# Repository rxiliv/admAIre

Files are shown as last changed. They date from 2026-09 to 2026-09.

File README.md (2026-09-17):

# AdmAIre: Wearable Assistance System for the Blind

AdmAIre is a cutting-edge wearable electronic device, in the form of a pair of simple glasses, designed to enhance the autonomy and safety of blind or visually impaired individuals. Through the integration of artificial intelligence and computer vision, the device analyzes the surrounding environment in real-time, providing interactive and intuitive voice assistance.

## Project Overview
The goal of AdmAIre is to bridge the gap between the user and the physical environment. Not only the system quickly detects the obstacles in the user's way, communicating essential information through an integrated audio interface, but it also allows the user to ask anything, as if they were talking to a person nearby, but keeping their full independence.

## System Architecture
The system is based on a low-latency circular data flow:
1. **Acquisition:** The wearable captures images (camera) and eventual voice inputs.
2. **Transmission:** Data is sent via **Wi-Fi connection** to the OpenRouter AI model (through the API).
3. **Processing:** The AI models process the data (Object Detection, OCR, Scene Description).
4. **Feedback:** The AI sends the text response back to the glasses, which plays it through the integrated output devices.

## Key Features

### Implemented Features

**Surroundings Analysis**
* **Object and Scene Recognition:** Real-time identification of potentially dangerous everyday elements.
* **Quick and Brief Alerts:** When near to obstacles, the device immediately detects the danger and warns the user.
* **Text Reading (OCR):** Ability to read labels, menus, or road signs in real-time.

**Well-thought-out Design**
* **Ergonomic Glasses:** Lightweight and discreet device, optimized for prolonged use.
* **No Hearing Obstruction:** Bone conduction speakers, studied to avoid obstructing the ears and keep the hearing unimpaired.
* **Customizable Frame and Structure:** Fully editable as one's wish, as the 3D model of the glasses are free to use and modify (check `license` for further information).

**Source-Available Project**

The project was made to be free for everyone to use, edit and improve, based on one's own preferences, ideas, and much more, as long as the project terms and conditions of the license, available in the `root` folder, are respected.

* **Source Code Available:** The microcontroller's C++ code is downloadable and editable.
* **Free-to-use 3D Model:** The eyeglasses frame is also available, ready for alterations, or directly for the 3D printer.
* **Guide for the Hardware:** The electrical schematics and the documentation is thought for people to understand how the prototype works and to use as they prefer.

### Planned Features
**Advanced Surroundings Analysis**
* **AI Voice Interface (NLP):** Two-way communication that allows the user to ask questions such as: *"Is there a free chair near me?"* or *"What bus number is arriving?"*.

**Advanced User Assistance**
* **Voice Activation:** The user can speak with the AI assistance through the phrase "Hey AdmAIre", captured by the integrated microphone.
* **API for Travel Details:** The AI assistance can give the user directions to get to a specific place when asked, through the implementation of an API.

## Technical Architecture

### Hardware
The prototype is based on the **XIAO ESP32-S3 Sense** microcontroller.
The electronic schematics may be found within the `pcb` folder.

**Components List**
* **Microcontroller:** Seeed Studio XIAO ESP32S3 Sense (with camera and microphone).
* **Battery:** LiPo 3.7V 803450 (1500mAh).
* **Audio Amplifiers:** MAX98357A I2S 3W DAC (x2).
* **Bone Conduction Speakers:** 8 Ohm Magnetic, 1W (x2).
* **Slide Switch:** Slide Switch (SPST) for power-on/off.
* **Resistors:** 100-200kΩ Resistors (x2).

The eyeglasses frame prototype is made through a 3D printer (PLA).
The 3D model is available in the `cad` folder, both as a one-piece and subdivided in `.stl` format, making it suitable for small 3D printers as well.

### Software
The main code resides in the microcontroller and can be found in the `firmware` folder.
The software is made through Arduino IDE.

**Code Content**
* **Microcontroller Code:** Code that allows the ESP32-S3 to send and receive radio signals, transmit the AI responses, and all the features mentioned above.
* **Simple HTML page:** Simple page for testing the device and debugging.

**Features and Technologies**
* **OpenRouter API:** Implementation of the OpenRouter API to use optimized AI models to analyze images and to respond to user queries in natural language.
* **Text-to-Speech (TTS) & STT:** Low-latency voice engines for fluid interaction.
* **Optimization of Energy Consumption:** Optimized code for minimal energy waste.

## Usage Instructions

To be able to recreate the prototype personally, all the information and resources are already present in the repository.
For the source code, the only things that need to be added are in `esp32s3.h`:
* **Wi-Fi SSID**: The name of the network the ESP32-S3 has to connect to. 
* **Wi-FI password**: The password of the network. 
* **OpenRouter API Key**: The API Key can be easily obtained from the OpenRouter services. 

**Please Note**: The AI model chosen by default in the source code is the Nvidia Nemotron 3 Nano Omni, a free model. Any other AI model that can have in input photos and audio and have text output can be used, as long as the code gets updated adequately.

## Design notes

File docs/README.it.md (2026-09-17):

# AdmAIre: Sistema di Assistenza Indossabile per i Non Vedenti

AdmAIre è un dispositivo elettronico indossabile all'avanguardia studiato per accrescere l'autonomia e la sicurezza delle persone non vedenti o ipovedenti. Con l'integrazione dell'intelligenza artificiale, il dispositivo analizza l'ambiente circostante in tempo reale, fornendo un'assistenza vocale interattiva e intuitiva.

## Panoramica del Progetto
L'obiettivo principale di AdmAIre è quello di creare un ponte solido tra l'utente e l'ambiente fisico. Questo sistema non solo rileva gli ostacoli di fronte all'utente, comunicando le informazioni essenziali attraverso un'interfaccia audio integrata, ma permette anche all'utente di chiedere qualunque cosa, come se stesse parlando con una persona accanto a sé, ma mantenendo la loro totale indipendenza.

## Architettura di Sistema
Il sistema è basato su un flusso di dati circolare a bassa latenza:
1. **Acquisizione:** Gli occhiali catturano immagini, attraverso la telecamera integrata, ed eventuali input vocali.
2. **Trasmissione:** I dati vengono trasmessi tramite **Connessione Wi-Fi** al modello AI di OpenRouter (tramite l'API).
3. **Elaborazione:** I modelli AI elaborano i dati (Object Detection, OCR, Scene Description).
4. **Feedback:** Il modello manda indietro la risposta in formato testo agli occhiali, che la riproducono tramite i dispositivi di output integrati.

## Funzionalità Chiave

### Funzionalità Attualmente Implementate

**Analisi delle Circostanze**
* **Riconoscimento di Oggetti e Scene:** Identificazione in tempo reale di elementi quotidiani che possono costituire un pericolo.
* **Avvisi Veloci e Brevi:** Quando l'utente si trova vicino ad ostacoli, il dispositivo rileva immediatamente il pericolo e avvisa l'utente.
* **Lettura di Testi (OCR):** Abilità di leggere etichette, menù o segnali stradali in tempo reale.

**Design Ben Pensato**
* **Occhiali Ergonomici:** Dispositivo leggero e discreto, ottimizzato per l'uso prolungato.
* **Nessuna Ostruzione all'Udito:** Altoparlanti a conduzione ossera, scelti per evitare di ostruire le orecchie e per mantenere l'udito efficiente.
* **Montatura e Struttura Personalizzabile:** Completamente modificabile in base alla propria volontà, in quanto il modello 3D degli occhiali sono utilizzabili gratuitamente (vedi `license` per maggiori informazioni).

**Progetto con Codice Sorgente Disponibile**

Il progetto è stato creato con l'intenzione di essere utilizzato, modificato e migliorato da tutti, in base alle proprie preferenze, idee, e tanto altro, affinché i termini e condizioni della licenza del progetto, presenti nella `root` della repository, siano rispettate.

* **Codice Sorgente Disponibile:** Il codice in C++ del microcontrollore è scaricabile e modificabile.
* **Modello 3D Utilizzabile Gratuitamente:** Anche la montatura degli occhiali è disponibile come modello 3D, pronto per alterazioni, o direttamente disponibile per la stampante 3D.
* **Guida per l'Hardware:** Lo schema elettrico e la documentazione sono pensati perché si possa capire come funzioni il prototipo e utilizzare a proprio piacimento.

### Funzionalità Previste in Futuro
**Analisi Avanzata delle Circostanze**
* **Interfaccia Vocale AI (NLP):** Comunicazione bidirezionale che permette all'utente di fare domande come: *"C'è una sedia libera vicino a me?"* or *"Che pullman sta arrivando?"*.

**Assistenza per Utenti Avanzata**
* **Attivazione Vocale:** L'utente può parlare con l'assistente AI attraverso la dicitura "Hey AdmAIre", individuata dal microfono integrato.
* **API per Dettagli di Viaggio:** L'assistenza AI può fornire indicazioni stradali per una destinazione specifica quando richiesto, tramite l'implementazione di un API apposita.

## Architettura Tecnica

### Hardware
Il prototipo è basato sul microcontrollore **XIAO ESP32-S3 Sense**.
Lo schema elettrico si può trovare nella cartella `pcb`.

**Lista dei Componenti**
* **Microcontrollore:** Seeed Studio XIAO ESP32S3 Sense (con modulo camera e microfono).
* **Batteria:** LiPo 3.7V 803450 (1500mAh).
* **Ampplificatori Audio:** MAX98357A I2S 3W DAC (x2).
* **Altoparlanti a Conduzione Ossea:** 8 Ohm Magnetic, 1W (x2).
* **Slide Switch:** Slide Switch (SPST) per accensione/spegnimento.
* **Resistori:** Resistori da 100-200kΩ (x2).

Il prototipo della montatura degli occhiali è pensato per essere stampato in 3D (PLA).
Il modello 3D è disponibile nella cartella `cad`, sia come modello a pezzo unico, sia suddiviso in moduli in formato `.stl`, rendendolo adatto anche a stampanti 3D di dimensioni ridotte.

### Software
Il codice principale risiede nel microcontrollor e può essere trovato nella cartella `firmware`.
Il software è creato con Arduino IDE.

**Contenuto del Codice**
* **Codice del Microcontrollore:** Codice che permette all'ESP32-S3 di inviare e ricevere segnali radio, trasmettere le risposte dell'AI, e tutte le funzionalità attaualmente presenti.
* **Pagina HTML Semplice:** Pagine semplice per testare il dispositivo e fare debugging.

**Tecnologie e Funzionalità**
* **API di OpenRouter:** Implementazione dell'API di OpenRouter per usufruire di modelli AI ottimizzati per analizzare immagini e rispondere alle necessità e domande dell'utente in linguaggio naturale.
* **Text-to-Speech (TTS) & STT:** Meccanismi di interazione vocale a bassa latenza.
* **Ottimizzazione del Consumo di Energia:** Codice ottimizzato per minimizzare lo spreco energetico.

## Istruzioni per l'Uso

Per poter ricreare il prototipo personalmente, tutte le informazioni e risorse sono già presenti all'interno della repository. 
Per quanto riguarda il codice sorgente, le uniche aggiunte che vanno apportate si trovano in `esp32s3.h`:
* **SSID del Wi-Fi:**: Il nome della rete a cui si connetterà l'ESP32-S3.
* **Password del Wi-Fi:** La password della rete.
* **Chiave API di OpenRouter:** La chiave API può essere facilmente ottenuta tramite i servizi di OpenRouter.

**N. B.:** Il modello AI utilizzato di default nel codice sorgente è l'Nvidia Nemotron 3 Nano Omni, un modello gratuito. Si può utilizzare qualunque altro modello AI che permette di prendere in input foto e audio e produrre in output testo, finché il codice venga aggiornato adeguatamente.

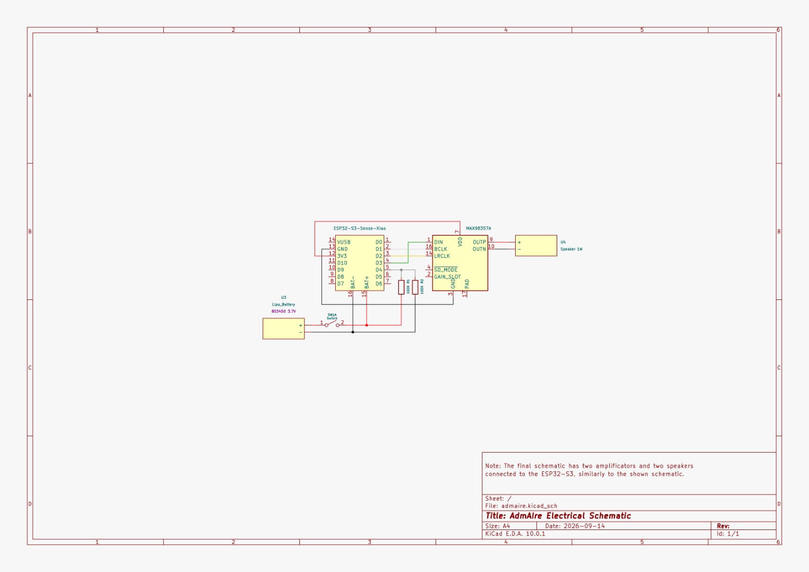
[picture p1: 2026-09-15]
hardware/pcb/admaire-electrical_schematic.png

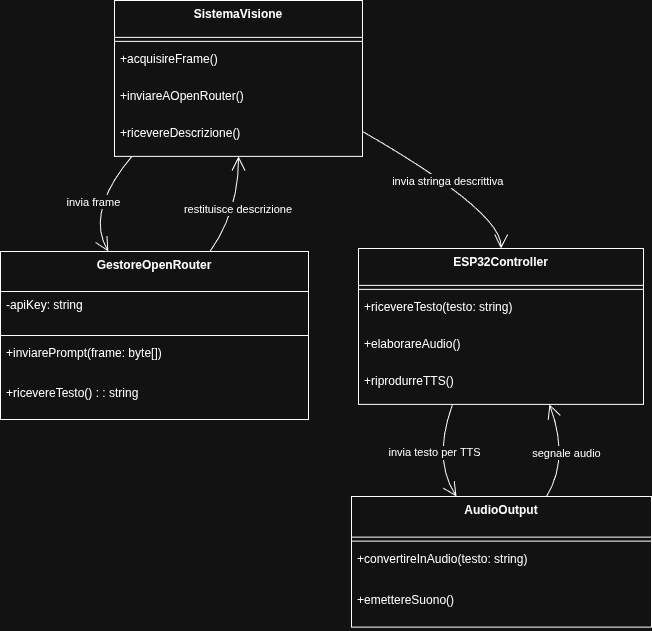
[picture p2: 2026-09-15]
software/diagrams/use-case-diagram.png

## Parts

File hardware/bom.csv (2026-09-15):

Reference | Qty | Desc | "Manufacturer"
R1,R2 | 2 | 100KΩ Resistor | ""
SW1 | 1 | Slide Switch | ""
U1 | 1 | ESP32-S3 XIAO Sense | "Seeed Studio"
U2 | 1 | MAX98357A I2S 3W Amplifier | "AZDelivery"
U3 | 1 | 3.7V 1600mAh Lipo Battery | "HXJNLDC"
U4 | 1 | 1W2 8Ω Speaker | "QUARKZMAN"

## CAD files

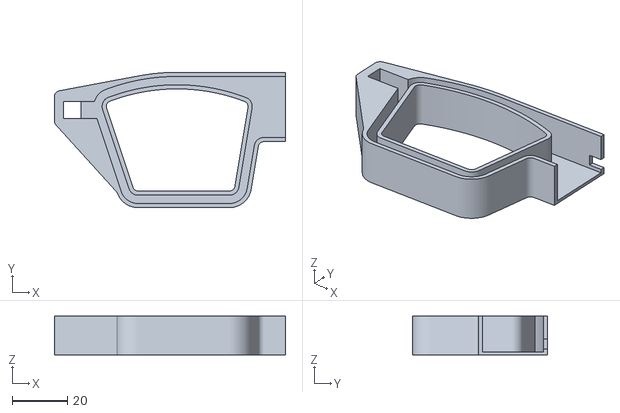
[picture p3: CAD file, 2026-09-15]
hardware/cad/stl/lens-frame1.stl
83.3 x 48.8 x 14.0

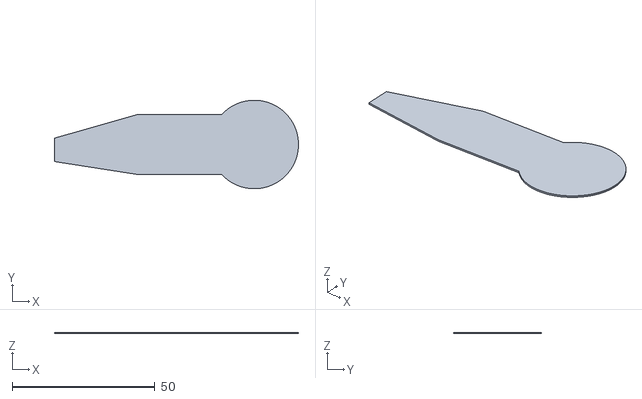
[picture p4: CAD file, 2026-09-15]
hardware/cad/stl/temple-cap2.stl
85.5 x 31.0 x 0.5

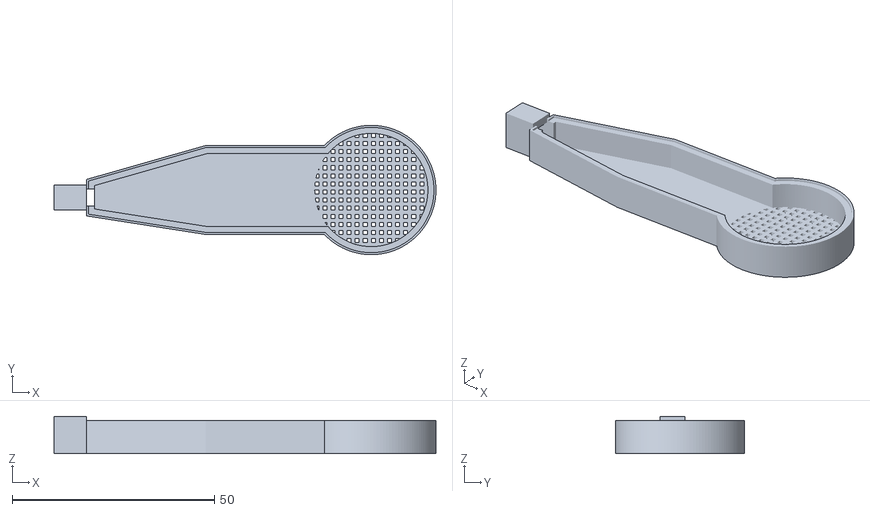
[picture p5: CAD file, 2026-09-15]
hardware/cad/stl/temple-tip2.stl
94.5 x 32.0 x 9.20

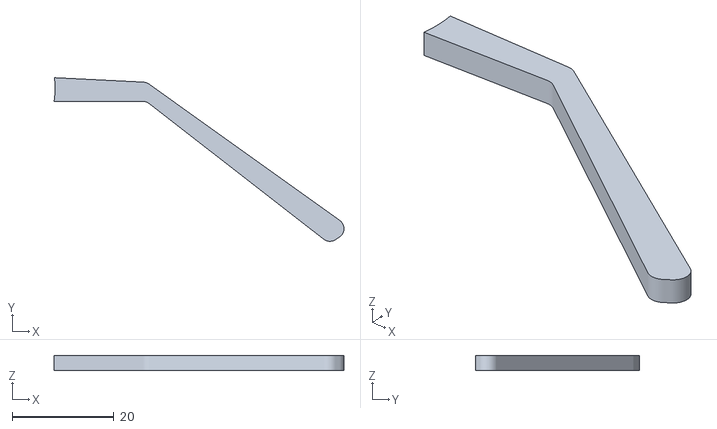
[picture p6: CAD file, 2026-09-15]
hardware/cad/stl/temple1.stl
57.0 x 32.2 x 3.00

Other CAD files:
hardware/cad/admaire.dwg
hardware/cad/stl/temple-cap1.stl
hardware/cad/stl/temple-tip1.stl
hardware/cad/stl/temple2.stl
hardware/cad/stl/lens-frame2.stl

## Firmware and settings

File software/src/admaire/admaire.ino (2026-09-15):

#include "Audio.h" 

#include "esp32s3.h"

// ==========================================
// ISTANZE GLOBALI
// ==========================================
Audio audio;
String testoCorrenteAudio = ""; // Buffer protetto per la RAM

void setup() {
    Serial.begin(115200);
    delay(2000); 
    Serial.println("--- AVVIO SISTEMA ADMAIRE ---");

    // Verifica PSRAM
    Serial.printf("[PSRAM] dimensione totale: %u byte, libera: %u byte\n",
                  ESP.getPsramSize(), ESP.getFreePsram());
    if (ESP.getPsramSize() == 0) {
        Serial.println("[PSRAM] ATTENZIONE: nessuna PSRAM rilevata! Controlla Tools > PSRAM in Arduino IDE.");
    }

    setCpuFrequencyMhz(160); 

    if (!inizializzaXiaoCamera()) {
        Serial.println("[ERRORE CRITICO] Inizializzazione modulo Camera fallita!");
        while (true) { delay(1000); }
    }
    Serial.println("[OK] Interfaccia Camera configurata.");

    WiFi.persistent(false);
    WiFi.disconnect(true);
    delay(500);
    
    WiFi.mode(WIFI_STA);
    WiFi.begin(ssid, password);
    
    Serial.print("[Wi-Fi] Connessione a " + String(ssid) + "...");
    while (WiFi.status() != WL_CONNECTED) {
        delay(500);
        Serial.print(".");
    }
    Serial.print("\n[OK] Connesso! IP: http://");
    Serial.println(WiFi.localIP());

    WiFi.setSleep(false);

    audio.setPinout(I2S_BCLK, I2S_LRC, I2S_DOUT);
    audio.setVolume(21); 

    // Test di Avvio
    audio.connecttospeech("Sistema pronto", "it");

    server.on("/", HTTP_GET, gestisciRoot);
    server.on("/capture", HTTP_GET, gestisciCattura);
    server.on("/analyze", HTTP_GET, gestisciAnalisi);
    server.on("/battery", HTTP_GET, gestisciBatteria);
    
    server.enableCORS(true); 
    server.begin();
    Serial.println("[SISTEMA] Pronti all'uso.");
}

void loop() {
    audio.loop();
    server.handleClient(); 

    if (testoDaVocalizzare != "") {
        // Per garantire la totale pulizia del Wi-Fi
        if (millis() - timestampRicezioneTesto > 2500) {
            testoCorrenteAudio = pulisciTesto(testoDaVocalizzare);
            testoDaVocalizzare = ""; 
            
            if (testoCorrenteAudio.length() > 0) {
                Serial.print("[AUDIO] Riproduzione voce in corso: ");
                Serial.println(testoCorrenteAudio);
                Serial.printf("[AUDIO] Heap libero prima del TTS: %u\n", ESP.getFreeHeap());

                if (audio.isRunning()) {
                    audio.stopSong();
                    delay(200);
                }

                bool avviato = audio.connecttospeech(testoCorrenteAudio.c_str(), "it");
                if (!avviato) {
                    Serial.println("[AUDIO] connecttospeech() ha restituito false, ritento tra 400ms");
                    delay(400);
                    avviato = audio.connecttospeech(testoCorrenteAudio.c_str(), "it");
                    Serial.printf("[AUDIO] Secondo tentativo: %s\n", avviato ? "OK" : "FALLITO");
                }
            }
        }
    }
}

// Callback diagnostico della libreria
void audio_info(const char *info) {
    Serial.print("[AUDIO INFO] ");
    Serial.println(info);
}

void audio_eof_speech(const char *info) {
    Serial.print("[AUDIO] Riproduzione terminata: ");
    Serial.println(info);
}

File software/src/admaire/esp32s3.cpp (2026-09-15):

#include "esp32s3.h"

WebServer server(80);

String testoDaVocalizzare = ""; 
unsigned long timestampRicezioneTesto = 0;

void gestisciRoot() {
    server.send_P(200, "text/html", PAGINA_HTML);
}

// Filtro del testo
String pulisciTesto(String testoSporco) {
    String pulito = testoSporco;
    pulito.replace("*", "");    
    pulito.replace("\"", "");   
    pulito.replace("#", "");    
    pulito.replace("\\n", " "); 
    pulito.replace("\n", " ");
    pulito.replace("\r", " ");
    pulito.trim();              
    return pulito;
}

void gestisciCattura() {
    camera_fb_t * fb = esp_camera_fb_get();
    if (!fb) { server.send(500, "text/plain", "ERRORE ACQUISIZIONE FOTO"); return; }
    size_t sizeBase64 = ((fb->len + 2) / 3) * 4 + 1;
    char *bufferBase64 = (char *)malloc(sizeBase64);
    size_t out_len = 0;
    mbedtls_base64_encode((unsigned char *)bufferBase64, sizeBase64, &out_len, fb->buf, fb->len);
    server.send(200, "text/plain", String(bufferBase64));
    free(bufferBase64);
    esp_camera_fb_return(fb);
}

// ============================================================================
// ENDPOINT AI - STAFFETTA MEMORIA E GESTIONE AUDIO SICURA
// ============================================================================
void gestisciAnalisi() {
    camera_fb_t * fb = esp_camera_fb_get();
    if (!fb) { 
        server.send(500, "text/plain", "Errore fotocamera"); 
        return;
    }

    size_t sizeBase64 = ((fb->len + 2) / 3) * 4 + 1;
    char *bufferBase64 = (char *)malloc(sizeBase64);
    size_t out_len = 0;
    mbedtls_base64_encode((unsigned char *)bufferBase64, sizeBase64, &out_len, fb->buf, fb->len);
    
    String payload;
    payload.reserve(sizeBase64 + 1000); 
    
    payload += "{\"model\":\"nvidia/nemotron-3-nano-omni-30b-a3b-reasoning:free\",\"max_tokens\":20,\"reasoning\":{\"enabled\":false},\"messages\":[{\"role\":\"user\",\"content\":[{\"type\":\"text\",\"text\":\"Sei l'assistente di un non vedente. Rispondi in italiano in modo telegrafico (massimo 8 parole). Indica solo l'ostacolo principale (strada rialzata, ostacoli). Altrimenti, rispondi 'via libera'.\"},{\"type\":\"image_url\",\"image_url\":{\"url\":\"data:image/jpeg;base64,";
    payload += bufferBase64;
    payload += "\"}}]}]}";
    
    free(bufferBase64);
    esp_camera_fb_return(fb);

    String responseText = "";

    // Allocazione standard
    {
        WiFiClientSecure client;
        client.setInsecure();
        
        HTTPClient http;
        http.setReuse(false); // Impedisce il blocco di rete post-chiamata
        http.begin(client, "https://openrouter.ai/api/v1/chat/completions");
        http.setTimeout(25000); 
        http.addHeader("Content-Type", "application/json");
        http.addHeader("Authorization", "Bearer " + String(openrouter_key));
        
        int httpCode = http.POST(payload);
        
        // Distruzione della foto
        payload = ""; 
        
        if (httpCode == 200) {
            String response = http.getString();
            int contentIdx = response.indexOf("\"content\"");
            if (contentIdx != -1) {
                int duePunti = response.indexOf(":", contentIdx);
                int avvioQuote = response.indexOf("\"", duePunti);
                if (avvioQuote != -1) {
                    int fineQuote = response.indexOf("\"", avvioQuote + 1);
                    while (fineQuote != -1 && response.charAt(fineQuote - 1) == '\\') {
                        fineQuote = response.indexOf("\"", fineQuote + 1);
                    }
                    responseText = response.substring(avvioQuote + 1, fineQuote);
                    responseText.replace("\\n", " ");
                    responseText.replace("\\\"", "");
                }
            }
        } else {
            String errBody = http.getString();
            Serial.print("[AI] Errore HTTP ");
            Serial.print(httpCode);
            Serial.print(": ");
            Serial.println(errBody);
            responseText = "Errore di rete: " + String(httpCode);
        }
        
        http.end(); 
        client.stop(); // Chiusura hardware della porta di rete
    } 

    // Avviso al telefono di non tenere la porta occupata
    server.sendHeader("Connection", "close");
    server.send(200, "text/plain", responseText);
    
    if (responseText != "" && !responseText.startsWith("Errore") && responseText != " via libera") {
        testoDaVocalizzare = responseText;
        timestampRicezioneTesto = millis();
    }
}

void gestisciBatteria() {
    uint32_t v = 0;
    for(int i=0; i<10; i++) { v += analogReadMilliVolts(PIN_BATTERIA); delay(5); }
    float vBat = (v / 10.0) * 2.0 / 1000.0; 
    bool inCarica = (vBat > 4.25);
    float pct = (vBat - 3.7) * 200.0;
    if(pct > 100.0) pct = 100.0; if(pct < 0.0) pct = 0.0;
    String tempoStimato = "";
    if (inCarica) {
        float oreRimaste = ((100.0 - pct) / 100.0) * 30.0;
        int h = (int)oreRimaste; int m = (int)((oreRimaste - h) * 60);
        tempoStimato = (pct >= 99.0) ? "Carica Completata" : "Circa " + String(h) + "h " + String(m) + "m al termine";
    } else {
        float oreRimaste = (pct / 100.0) * 10.0;
        int h = (int)oreRimaste; int m = (int)((oreRimaste - h) * 60);
        tempoStimato = (pct <= 5.0) ? "Batteria Scarica! Collegare l'alimentatore." : "Circa " + String(h) + "h " + String(m) + "m rimanenti";
    }
    String jsonResponse = "{\"pct\":" + String((int)pct) + ",\"charging\":" + (inCarica ? "true" : "false") + ",\"time\":\"" + tempoStimato + "\"}";
    server.sendHeader("Connection", "close");
    server.send(200, "application/json", jsonResponse);
}

// ============================================================================
// INIZIALIZZAZIONE FOTOCAMERA E AUDIO
// ============================================================================
bool inizializzaXiaoCamera() {
    camera_config_t config;
    config.ledc_channel = LEDC_CHANNEL_0;
    config.ledc_timer = LEDC_TIMER_0;
    config.pin_d0 = Y2_GPIO_NUM;
    config.pin_d1 = Y3_GPIO_NUM;
    config.pin_d2 = Y4_GPIO_NUM;
    config.pin_d3 = Y5_GPIO_NUM;
    config.pin_d4 = Y6_GPIO_NUM;
    config.pin_d5 = Y7_GPIO_NUM;
    config.pin_d6 = Y8_GPIO_NUM;
    config.pin_d7 = Y9_GPIO_NUM;
    config.pin_xclk = XCLK_GPIO_NUM;
    config.pin_pclk = PCLK_GPIO_NUM;
    config.pin_vsync = VSYNC_GPIO_NUM;
    config.pin_href = HREF_GPIO_NUM;
    config.pin_sccb_sda = SIOD_GPIO_NUM;
    config.pin_sccb_scl = SIOC_GPIO_NUM;
    config.pin_pwdn = PWDN_GPIO_NUM;
    config.pin_reset = RESET_GPIO_NUM;
    config.xclk_freq_hz = 20000000;
    config.pixel_format = PIXFORMAT_JPEG;
    config.frame_size = FRAMESIZE_QVGA;  
    config.jpeg_quality = 10;            
    config.fb_count = 1;                 
    config.fb_location = CAMERA_FB_IN_PSRAM; 
    config.grab_mode = CAMERA_GRAB_LATEST;

    esp_err_t err = esp_camera_init(&config);
    return (err == ESP_OK);
}

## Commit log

2026-09-15 Add Software and Hardware Files
    [admaire-electrical_schematic.kicad_sch]
2026-09-15 Rename folders and Add sections
    [admaire-electrical_schematic.kicad_sch]
2026-09-15 Add ESP32-S3 source code
2026-09-15 Add BOM and Update README
    [bom.csv]
2026-09-15 Add Eyeglass Frame Model
    [admaire.dwg, lens-frame1.stl, lens-frame2.stl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]
2026-09-15 Fixed bugs in code
    [admaire.ino, esp32s3.cpp, esp32s3.h]
